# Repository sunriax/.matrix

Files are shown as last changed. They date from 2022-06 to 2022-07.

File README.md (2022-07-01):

 

# . Matrix Display Controller

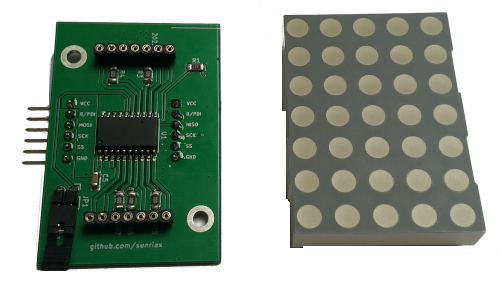
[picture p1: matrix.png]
PCB


The MDC (Matrix Display Controller) is to interact with a dot matrix display (like the [Kingbright TA20](https://at.rs-online.com/web/p/led-displays/4516650?sra=pmpn)) over `SPI` bus or `UART` (See the command list below).

# Board

| Download | Description |
|---|:---:|
| [Schematic](https://cadlab.io/project/25253/main/circuit/UENCL21hdHJpeC5raWNhZF9zY2g%3D) | Complete Schematic of the Display|
| [KiCAD](https://cadlab.io/project/25253/main/circuit/UENCL21hdHJpeC5raWNhZF9wY2I%3D) | KiCAD files |
| [Gerber](https://cadlab.io/project/25253/main/circuit/UENCL21hdHJpeC5raWNhZF9wY2I%3D) | Gerber production and drill files |

## 3D Model

| TOP | BOT |
|-----|-----|
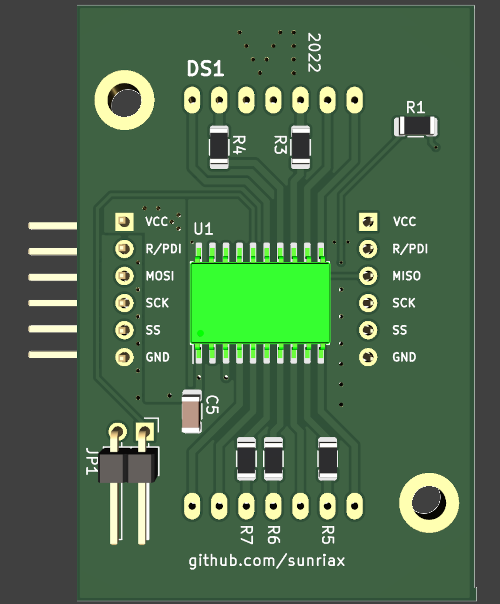
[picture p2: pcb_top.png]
PCB Top
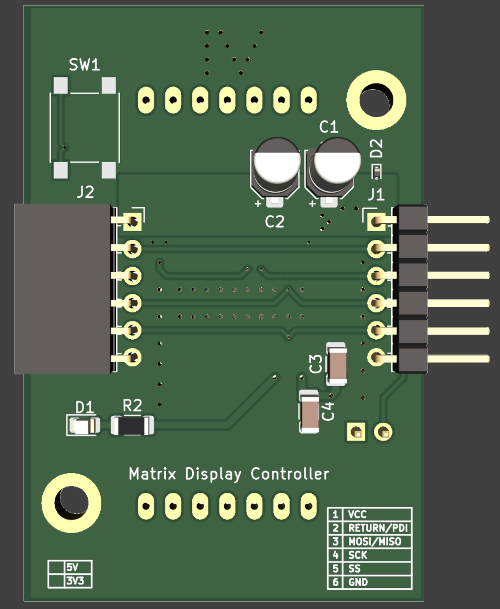
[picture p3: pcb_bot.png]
PCB Bot
|  |  | 

## Agenda

| Board | Status |
|---|:---:|
| [Schematic](https://cadlab.io/project/25253/main/circuit/UENCL21hdHJpeC5raWNhZF9zY2g%3D) | ✔️ Done |
| [Board](https://cadlab.io/project/25253/main/circuit/UENCL21hdHJpeC5raWNhZF9wY2I%3D) | ✔️ Done |
| [Partlist](./PCB/docs/matrix.csv) | ✔️ Done |
| Production | ✔️ Done |
| [Assembly](pcb.png) | ✔️ Done |
| Case | ❌ Open |

# Firmware 

| Image | Download |
|---|---|
| Display | [zip](https://github.com/sunriax/.matrix/releases/latest/download/matrix-firmware.zip) / [tar.gz](https://github.com/sunriax/.matrix/releases/latest/download/matrix-firmware.tar.gz) |
| Demo (ATmega16) | [zip](https://github.com/sunriax/.matrix/releases/latest/download/test-firmware-atmega16a.zip) / [tar.gz](https://github.com/sunriax/.matrix/releases/latest/download/test-firmware-atmega16a.tar.gz) |

# Display

The display can be driven in two modes either the standard (`spi`) mode or the `uart` mode.

## SPI mode

The display can be controlled with the `matrix` library. The library can be found in the [TEST project](./Firmware/TEST/main.c). The library is modular and can be adapted onto other plattforms. For platform adaptions the `spi` library has to be rewritten for the target platform. Currently the library can be used with an `ATmega16A`.

### Startup

``` c
// User libraries
#include "matrix/matrix.h"

// ...
int main(void)
{
	matrix_init();
	_delay_ms(1000);
	matrix_clear_all();
	_delay_ms(1000);
}
```

### Standard commands

| Command | Description |
|---|---|
| `matrix_init()` | Initializes the display |
| `matrix_buffer(0-255, ARRAY)` | Send an array (5*7) bits to a specific display |
| `matrix_buffer_all(ARRAY)` | Send an array (5*7) bits to all displays |
| `matrix_char(0-255, ASCII)` | Send an ASCII char to a specific display |
| `matrix_string(STRING)` | Send an ASCII string to a all display |
| `matrix_clear(0-255)` | Clear a specific display |
| `matrix_clear_all()` | Clear all displays |

### Speical commands

| Define | VALUE | Description |
|---|---|---|
| `MATRIX_EEPROM_CHAR0`  | `0x00`  | EEPROM address of MEMORY 0 |
| `MATRIX_EEPROM_CHAR0`  | `0x01`  | EEPROM address of MEMORY 1 |
| ... | ... | ... |
| `MATRIX_EEPROM_CHAR0`  | `0x0E`  | EEPROM address of MEMORY E |
| `MATRIX_EEPROM_CHAR0`  | `0x0F`  | EEPROM address of MEMORY F |

| Command | Description |
|---|---|
| `matrix_prom_write(0-255, DEFINE, ARRAY)` | Save an array (5*7) to the display EEPROM |
| `matrix_prom_read(0-255, DEFINE)` | Load an array from EEPROM to the display |

### Example

``` c
// TEST Connection
//
//          uC                 DISPLAY 0              DISPLAY 1
//  ~~~~~~~~~~~~~~~~~+    +~~~~~~~~~~~~~~~~~+    +~~~~~~~~~~~~~~~~~+
//    A  (M)         |    |                 |    |                 |
//    T  (E)     VCC +----+ VCC         VCC +----+ VCC         VCC |
//    M  (G)         |    |                 |    |                 |
//    E  (A)    MOSI +----+ MOSI       MISO +----+ MOSI       MISO |
//    G  (C)     SCK +----+ SCK         SCK +----+ SCK         SCK |
//    A  (A)      SS +----+ SS           SS +----+ SS           SS |
//    1  (R)     GND +----+ GND         GND +----+ GND         GND |
//    6  (D)         |    |                 |    |                 |
//    A              |    +~~~~~~~~~~~~~~~~~+    +~~~~~~~~~~~~~~~~~+
//  ~~~~~~~~~~~~~~~~~+

#define F_CPU 12000000UL    // System clock (required for delay)

// System libraries
#include <avr/io.h>
#include <util/delay.h>

// User libraries
#include "matrix/matrix.h"

// ...
int main(void)
{
	matrix_init();
	_delay_ms(1000);
	matrix_clear_all();
	_delay_ms(1000);

    unsigned char buffer[] = {
		0b01000,
		0b01000,
		0b01000,
		0b01000,
		0b01000,
		0b01000,
		0b11111
	}; 

    // Send buffer to display 0
    matrix_buffer(0, buffer);
	_delay_ms(1000);

    // Send buffer to all displays
    matrix_buffer_all(buffer);
	_delay_ms(1000);

    // Send ASCII char to display 0
    matrix_char(0, 'A');
	_delay_ms(1000);

    // Send string to displays
    matrix_string(0, "TEST");
	_delay_ms(1000);

    // Clear display 0
    matrix_clear(0);
	_delay_ms(1000);

    // Clear all displays
    matrix_clear_all();
	_delay_ms(1000);

    // !!! Only one time necessary !!!
    // !!!!!!!!!!!!!!!!!!!!!!!!!!!!!!!!!!!!!!!!!!!!!!!!!!!
    // !!! Warning:                                    !!!
    // !!! Don´t call this function in a while(1) loop !!!
    // !!! This will damage the EEPROM                 !!!
    // !!!!!!!!!!!!!!!!!!!!!!!!!!!!!!!!!!!!!!!!!!!!!!!!!!!

    // Save buffer in display EEPROM
	matrix_prom_write(0, MATRIX_EEPROM_CHAR0, buffer);
	_delay_ms(1000);

    // Read data from EEPROM
    matrix_prom_read(0, MATRIX_EEPROM_CHAR0);
	_delay_ms(1000);
}
```

## UART mode

The standard ASCII characters can also be transferred to display over UART. Therefore a special configuration is necessary. Pin `SS` should be connected to ground (`GND`) before powering the display.

``` c
// TEST Connection
//
//           DISPLAY 0              USB/UART
//      +~~~~~~~~~~~~~~~~~+   +~~~~~~~~~~~~~~~~~+
//      |                 |   |                 |
//      + VCC         VCC +---+ VCC             |
//      |                 |   |             +---+
//      + MOSI       MISO +---+ TXD         | U |
//      + SCK         SCK +   |             | S |
//  +---+ SS           SS +   |             | B |
//  +---+ GND         GND +---+ GND         +---+
//      |                 |   |                 |
//      +~~~~~~~~~~~~~~~~~+   +~~~~~~~~~~~~~~~~~+
```

Characters can be sent to the display over [TeraTerm](https://osdn.net/projects/ttssh2/releases/) or [Putty](https://www.chiark.greenend.org.uk/~sgtatham/putty/latest.html)
`UART` should contain following setup:

| Parameter | Value |
|---|---|
| Baudrate  | 9600  |
| Datasize  | 8 Bit |
| Parity | None  |
| Stopbits  | 1 |

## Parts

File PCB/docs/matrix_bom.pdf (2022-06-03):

ID Bezeichner Gehäuse | Stückzahl Bezeichnung/Wert
1 R2 | R_1206_3216Metric | 1 140 | DigiKey | RMCF1206FT140R
2 R5,R3,R4,R6,R7R_1206_3216Metric | 5 0 | Magazin -
3 JP1 | PinHeader_1x02_P2.54mm_Horizontal | 1 | RS | siehe Pos. 14
4 H1,H2 | MountingHole_3.2mm_M3_DIN965_Pad | 2 | - | -
5 C5 | C_1206_3216Metric | 1 10n | RS | 264-4141
6 DS1 | DIPS3810W50P254L3765H870Q14N | 1 TA20-11SRWA | RS | 451-6650
7 U1 | SOIC-20W_7.5x12.8mm_P1.27mm | 1 ATtiny406-S | DigiKey | ATTINY406-SNRTR-ND
8 R1 | R_1206_3216Metric | 1 330 | RS | 223-2186
9 C4,C3 | C_1206_3216Metric | 2 100n | RS | 133-5654
10 D1 | LED_0805_2012Metric | 1 LED | RS | 654-5773
11 SW1 | SW_SPST | 1 Taster SMD Megacard | RS | 479-1491
12 C2,C1 | CP_Elec_4x5.8 | 2 10u | RS | 565-633
13 J2 | PinSocket_1x06_P2.54mm_Horizontal | 1 Conn_01x06_Female | RS | 765-5676
14 J1 | PinHeader_1x06_P2.54mm_Horizontal | 1 Conn_01x06_Male | RS | 251-8654
15 | Buchsenleiste | 2 | RS | 267-7400

Anbieter und Referenz

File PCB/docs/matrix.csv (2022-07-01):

ID | Bezeichner | Gehäuse | Stückzahl | Bezeichnung | Anbieter und Referenz
1 | R2 | R_1206_3216Metric | 1 | 140 | DigiKey | RMCF1206FT140R | Digikey
2 | R5/R3/R4/R6/R7 | R_1206_3216Metric | 5 | 0
3 | JP1 | PinHeader_1x02_P2.54mm_Horizontal | 1 |  | RS | siehe Pos. 14 | RS
4 | H1/H2 | MountingHole_3.2mm_M3_DIN965_Pad | 2
5 | C5 | C_1206_3216Metric | 1 | 10n | RS | 264-4141 | RS
6 | DS1 | DIPS3810W50P254L3765H870Q14N | 1 | TA20-11SRWA | RS | 451-6650 | RS
7 | U1 | SOIC-20W_7.5x12.8mm_P1.27mm | 1 | ATtiny406-S | DigiKey | ATTINY406-SNRTR-ND | DigiKey
8 | R1 | R_1206_3216Metric | 1 | 330 | RS | 223-2186 | RS
9 | C4/C3 | C_1206_3216Metric | 2 | 100n | RS | 133-5654 | RS
10 | D1 | LED_0805_2012Metric | 1 | LED | RS | 654-5773 | RS
11 | SW1 | SW_SPST | 1 | SW_Push | RS | 479-1491 | RS
12 | C2/C1 | CP_Elec_4x5.8 | 2 | 10u | RS | 565-633 | RS
13 | J2 | PinSocket_1x06_P2.54mm_Horizontal | 1 | Conn_01x06_Female | RS | 765-5676 | RS
14 | J1 | PinHeader_1x06_P2.54mm_Horizontal | 1 | Conn_01x06_Male | RS | 251-8654 | RS
15 |  | Buchsenleiste | 2 |  | RS | 267-7400 | RS
16 |  | Leiterplatte | 50 | 76 |  |  | multi-cb

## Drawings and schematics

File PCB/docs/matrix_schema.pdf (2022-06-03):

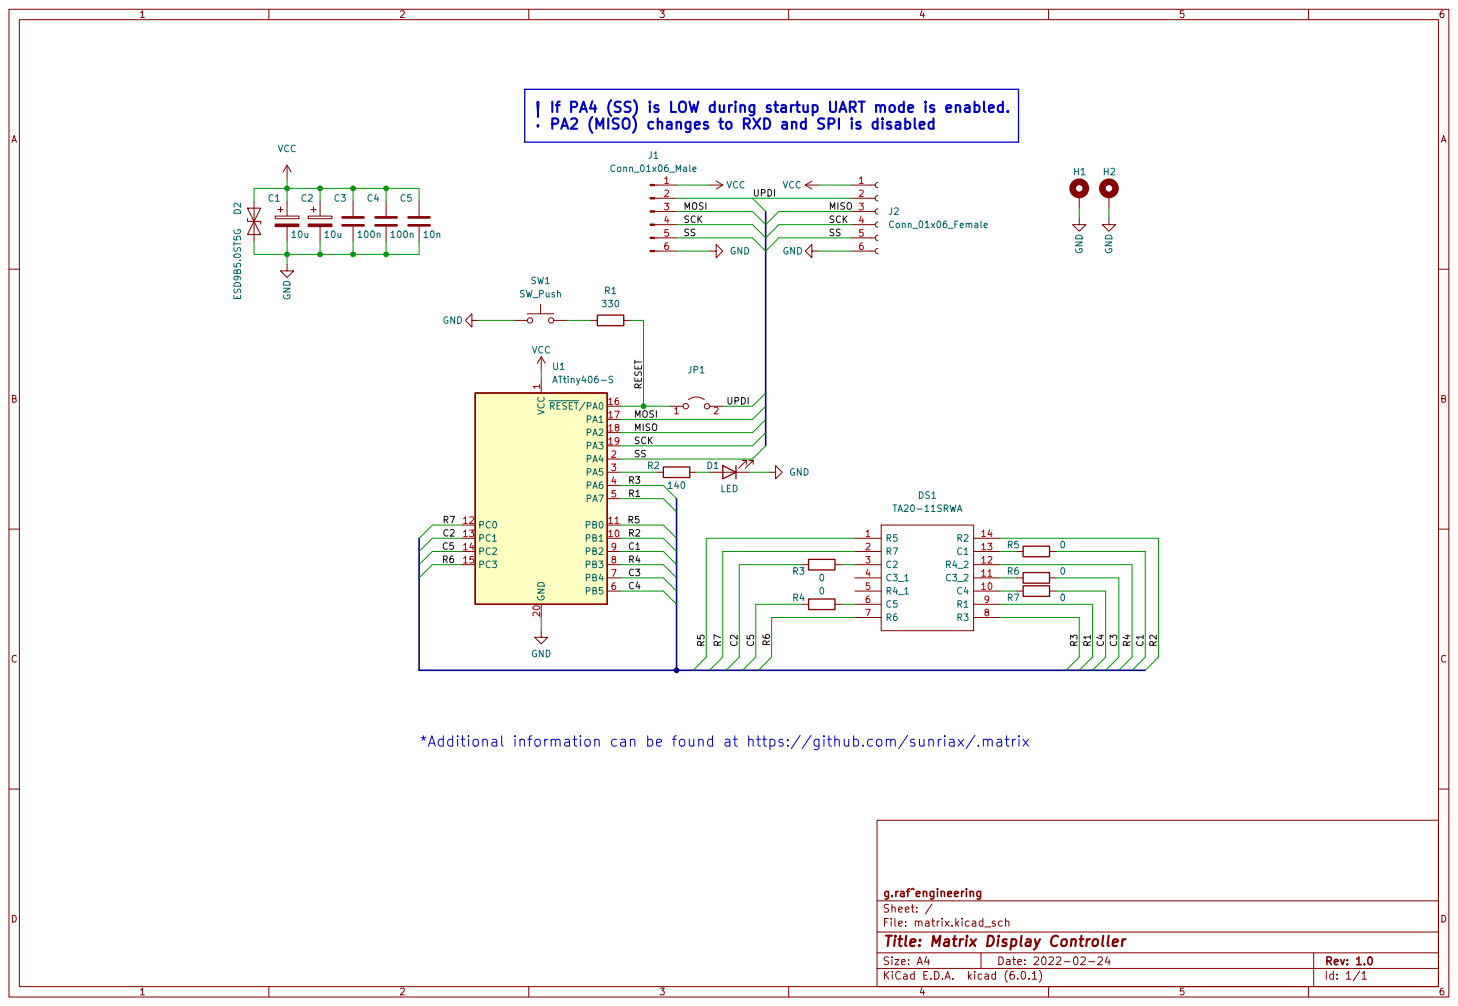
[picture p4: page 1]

If PA4 (SS) is LOW during startup UART mode is enabled.
PA2 (MISO) changes to RXD and SPI is disabled
VCCGND GND

*Additional information can be found at https://github.com/sunriax/.matrix

File: matrix.kicad_sch Sheet: / g.raf^engineering

Id: 1/1 Title: Matrix Display Controller

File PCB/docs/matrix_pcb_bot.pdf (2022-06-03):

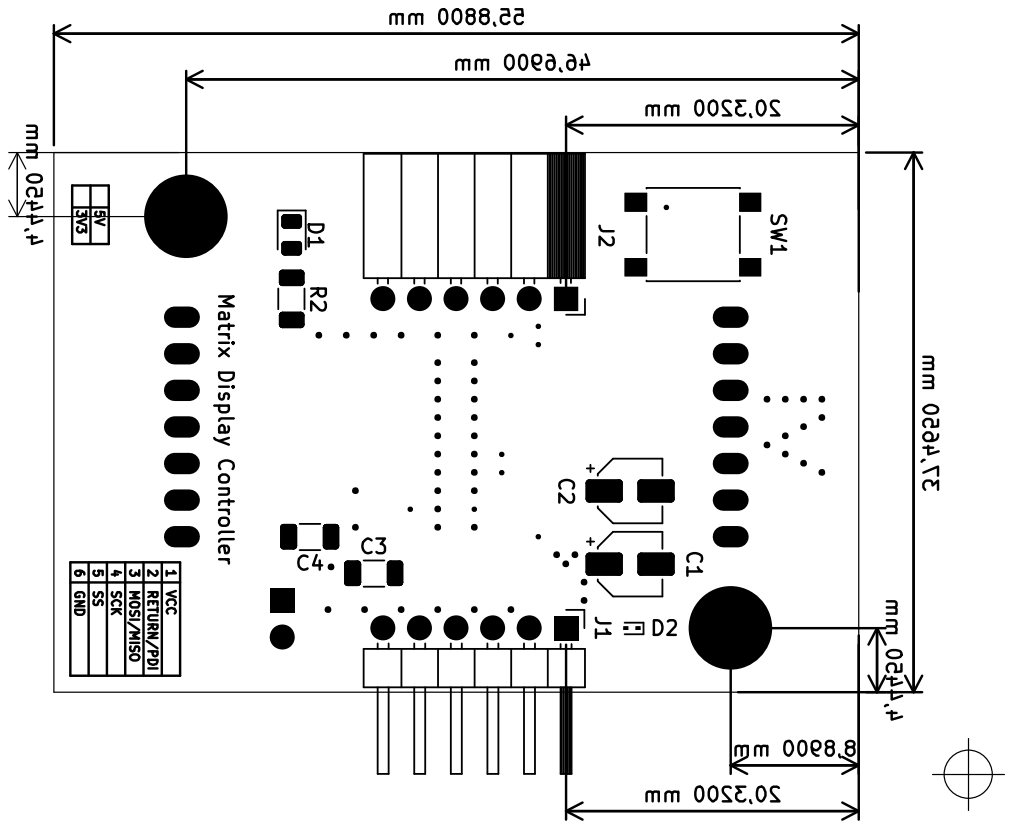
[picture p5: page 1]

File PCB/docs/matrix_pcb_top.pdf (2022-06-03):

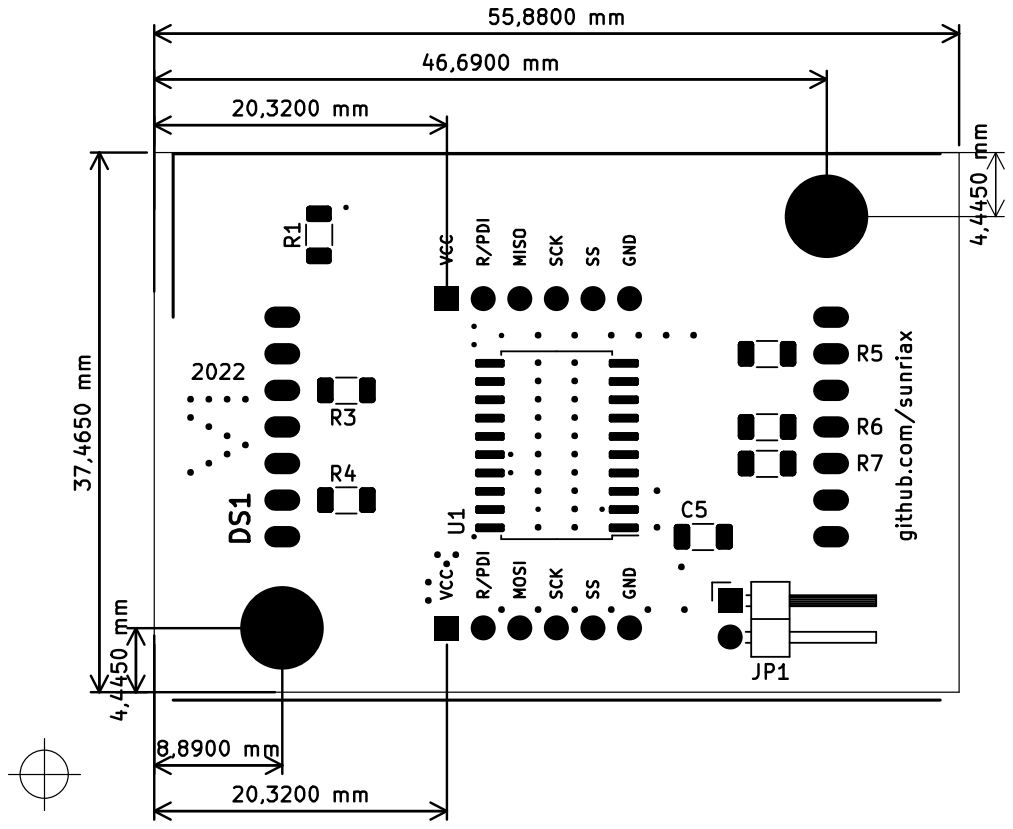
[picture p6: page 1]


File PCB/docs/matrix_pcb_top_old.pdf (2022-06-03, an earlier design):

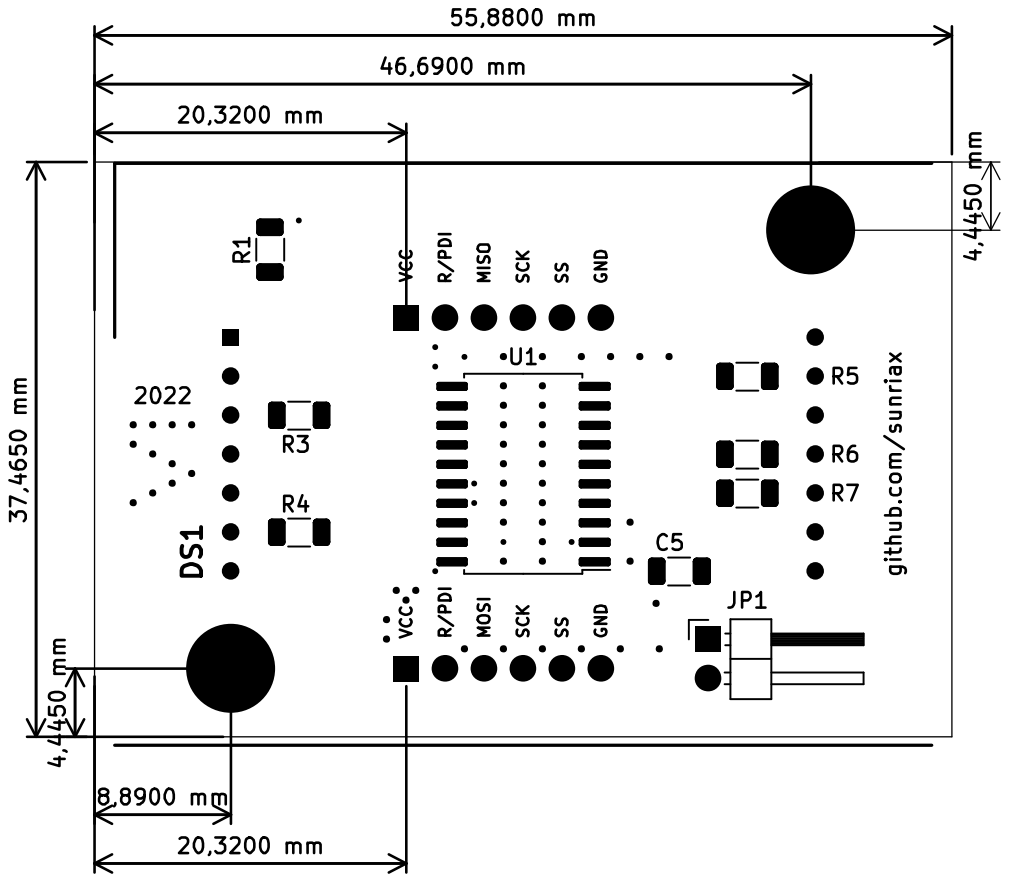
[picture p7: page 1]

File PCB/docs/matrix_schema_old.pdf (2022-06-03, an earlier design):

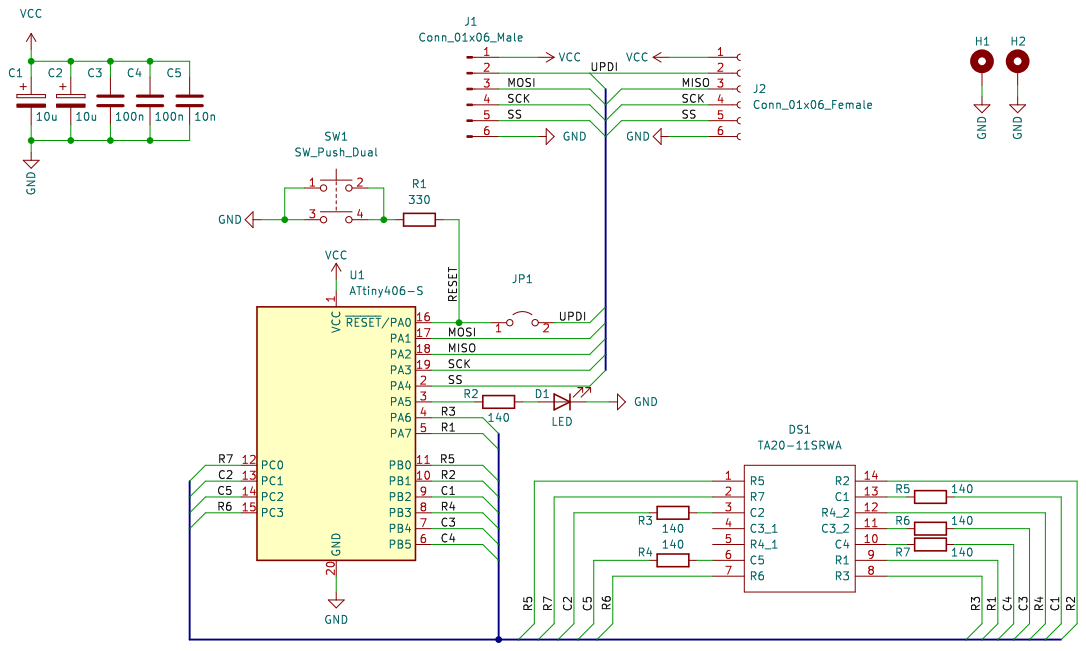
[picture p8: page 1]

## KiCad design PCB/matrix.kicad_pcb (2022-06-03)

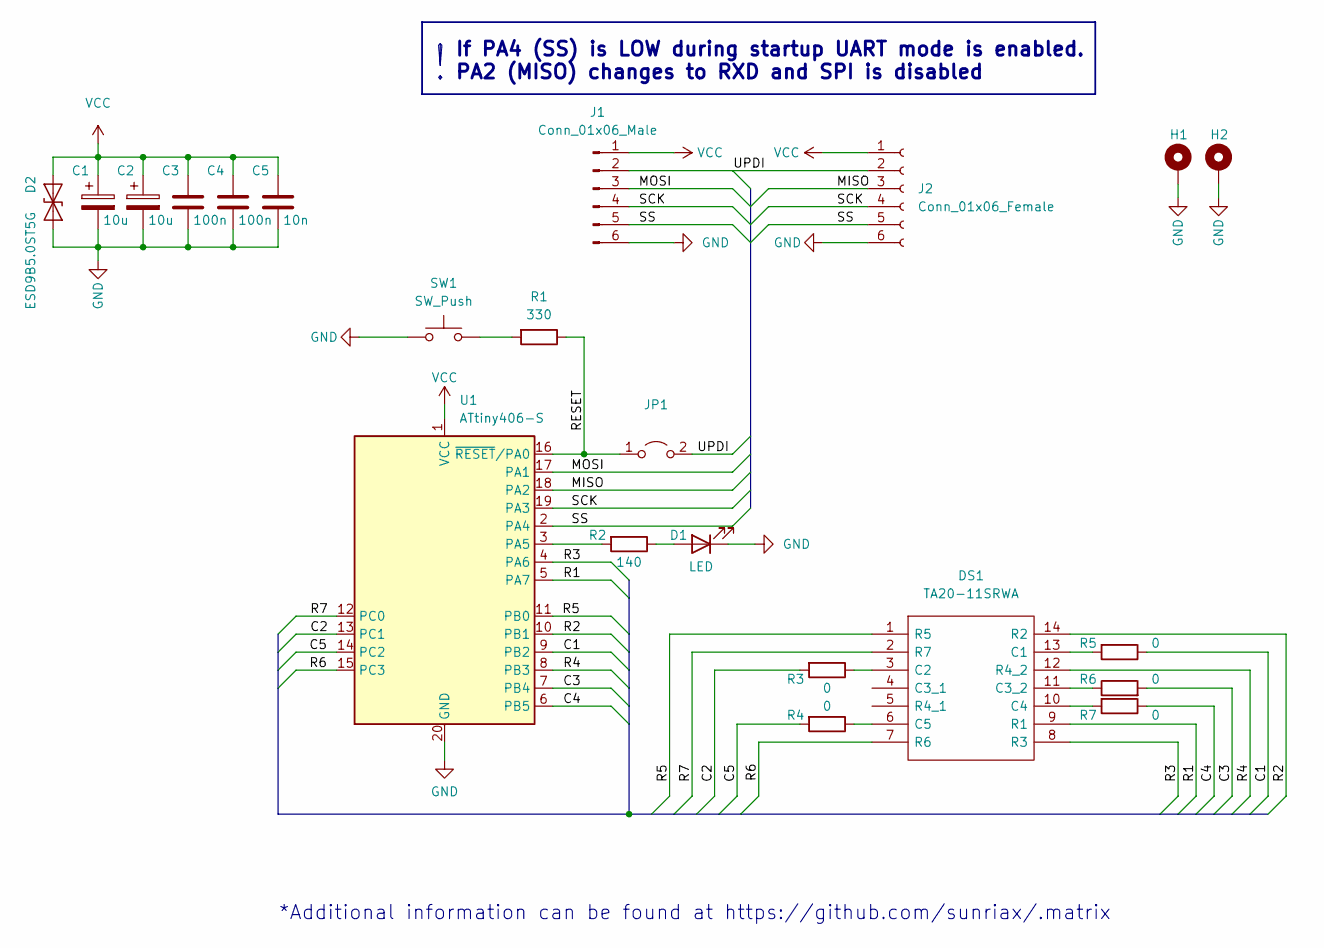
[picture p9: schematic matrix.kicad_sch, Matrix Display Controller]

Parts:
C1, C2: 10u; CP_Elec_4x5.8
C3, C4: 100n; C_1206_3216Metric
C5: 10n; C_1206_3216Metric
D1: LED; LED_0805_2012Metric
D2: ESD9B5.0ST5G; D_SOD-923
DS1: TA20-11SRWA; DIPS3810W50P254L3765H870Q14N; Manufacturer_Part_Number TA20-11SRWA; Mouser Part Number 604-TA20-11SRWA
H1, H2: MountingHole_3.2mm_M3_DIN965_Pad
J1: Conn_01x06_Male; PinHeader_1x06_P2.54mm_Horizontal
J2: Conn_01x06_Female; PinSocket_1x06_P2.54mm_Horizontal
JP1: PinHeader_1x02_P2.54mm_Horizontal
R1: 330; R_1206_3216Metric
R2: 140; R_1206_3216Metric
R3, R4, R5, R6, R7: 0; R_1206_3216Metric
SW1: SW_Push; SW_Push_1P1T_NO_6x6mm_H9.5mm
U1: ATtiny406-S; SOIC-20W_7.5x12.8mm_P1.27mm

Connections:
/C1: R5.1, U1.9 (PB2)
/C2: R3.2, U1.13 (PC1)
/C3: R6.2, U1.7 (PB4)
/C4: R7.1, U1.6 (PB5)
/C5: R4.2, U1.14 (PC2)
/MISO: J2.3, U1.18 (PA2)
/MOSI: J1.3, U1.17 (PA1)
/R1: DS1.9 (R1), U1.5 (PA7)
/R2: DS1.14 (R2), U1.10 (PB1)
/R3: DS1.8 (R3), U1.4 (PA6)
/R4: DS1.12 (R4_2), U1.8 (PB3)
/R5: DS1.1 (R5), U1.11 (PB0)
/R6: DS1.7 (R6), U1.15 (PC3)
/R7: DS1.2 (R7), U1.12 (PC0)
/RESET: JP1.1 (A), R1.1, U1.16 (~RESET/PA0)
/SCK: J1.4, J2.4, U1.19 (PA3)
/SS: J1.5, J2.5, U1.2 (PA4)
/UPDI: J1.2, J2.2, JP1.2 (B)
GND: C1.2, C2.2, C3.2, C4.2, C5.2, D1.1 (K), D2.1 (A1), H1.1, H2.1, J1.6, J2.6, SW1.1, U1.20 (GND)
unnamed: D1.2 (A), R2.1
unnamed: DS1.3 (C2), R3.1
unnamed: DS1.6 (C5), R4.1
unnamed: DS1.10 (C4), R7.2
unnamed: DS1.11 (C3_2), R6.1
unnamed: DS1.13 (C1), R5.2
unnamed: R1.2, SW1.2
unnamed: R2.2, U1.3 (PA5)
VCC: C1.1, C2.1, C3.1, C4.1, C5.1, D2.2 (A2), J1.1, J2.1, U1.1 (VCC)

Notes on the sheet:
*Additional information can be found at https://github.com/sunriax/.matrix
If PA4 (SS) is LOW during startup UART mode is enabled. PA2 (MISO) changes to RXD and SPI is disabled

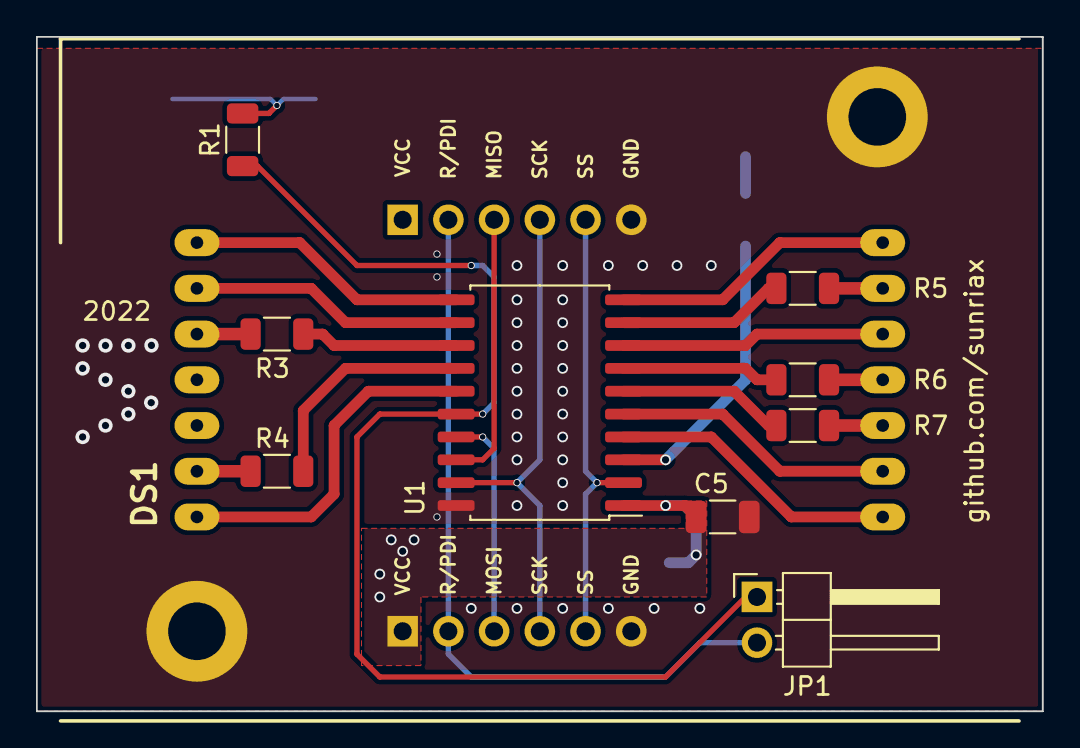
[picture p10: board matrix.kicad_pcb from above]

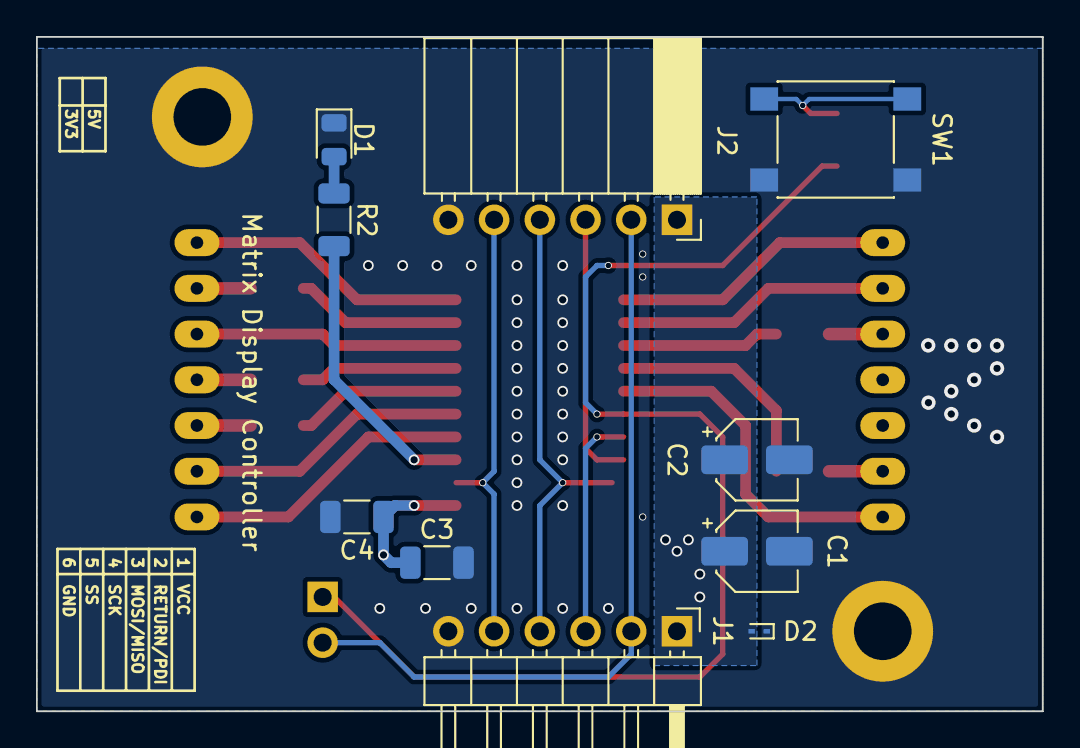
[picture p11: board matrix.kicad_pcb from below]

Board: 2 copper layers, 55.9 x 37.5 mm, 22 parts (10 on the bottom side), 28 nets.

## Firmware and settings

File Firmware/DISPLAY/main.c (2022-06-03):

/* -----------------------------------------
 * G.Raf^engineering
 * www.sunriax.at
 * -----------------------------------------
 *    Platform: .matrix display controller
 *    Hardware: ATtiny406
 * -----------------------------------------
 *     Version: 1.0 Release
 *      Author: G.Raf
 * Description:
 *   .matrix display controller firmware
 * -----------------------------------------
 */ 

#define F_CPU 20000000UL

#define BAUDRATE 9600UL
// #define USE_U2X

#ifdef USE_U2X
	#define USART0_BAUD_RATE(BAUD_RATE) ((float)(F_CPU * 64 / (8 * (float)BAUD_RATE)) + 0.5)
#else
	#define USART0_BAUD_RATE(BAUD_RATE) ((float)(F_CPU * 64 / (16 * (float)BAUD_RATE)) + 0.5)
#endif

#define TIMER_PER 0x04FF

#include <avr/io.h>
#include <avr/cpufunc.h>
#include <avr/interrupt.h>
#include <util/delay.h>

#include "matrix/matrix.h"

volatile unsigned char spi_buffer;
volatile unsigned char spi_command;
volatile unsigned char spi_pointer;

volatile unsigned char pixel_x;
volatile unsigned char pixel_y;

volatile unsigned char copy;

volatile unsigned char eeprom_save;
volatile unsigned char eeprom_load;

volatile unsigned char matrix[] = {
	0b00000,
	0b00000,
	0b00000,
	0b00000,
	0b00000,
	0b00000,
	0b00000
};

ISR(PORTA_PORT_vect)
{
	sei();	// Allow nested interrupts

	// DATA transfer led
	PORTA.OUTTGL = PIN5_bm;

	spi_pointer++;

	if(spi_pointer % 2)
	{
		spi_command = spi_buffer;
	}
	else
	{
		spi_buffer;
		spi_pointer = 0;
	
		switch (spi_command)
		{
			case 0x01:	// ROW 1
			case 0x02:	// ROW 2
			case 0x03:	// ROW 3
			case 0x04:	// ROW 4
			case 0x05:	// ROW 5
			case 0x06:	// ROW 6
			case 0x07:	// ROW 7
				matrix[(spi_command - 1)] = spi_buffer;
			break;
			case 0x08:	// Initiate ASCII copy
				copy = spi_buffer;
			break;
			case 0x09:	// CLEAR
				matrix_clear_buffer(matrix);
			break;
			case 0x10:	// Display On/Off
				if(0x01 & spi_buffer)
				{
					TCA0.SINGLE.CTRLA |= TCA_SINGLE_ENABLE_bm;
				}
				else
				{
					TCA0.SINGLE.CTRLA &= ~TCA_SINGLE_ENABLE_bm;
					matrix_row_clear();
					matrix_column_clear();
				}
			break;
			case 0x20:	// Display EEPROM
			case 0x21:
			case 0x22:
			case 0x23:
			case 0x24:
			case 0x25:
			case 0x26:
			case 0x27:
			case 0x28:
			case 0x29:
			case 0x2A:
			case 0x2B:
			case 0x2C:
			case 0x2D:
			case 0x2E:
			case 0x2F:
				eeprom_load = spi_command;
			break;
			case 0x30:	// Copy matrix content to EEPROM
			case 0x31:
			case 0x32:
			case 0x33:
			case 0x34:
			case 0x35:
			case 0x36:
			case 0x37:
			case 0x38:
			case 0x39:
			case 0x3A:
			case 0x3B:
			case 0x3C:
			case 0x3D:
			case 0x3E:
			case 0x3F:
				eeprom_save = spi_command;
			break;
			default:
			break;
		}
		
		spi_command = 0x00;
	}
	
	PORTA.INTFLAGS = PIN4_bm;
}

ISR(TCA0_OVF_vect)
{
	matrix_row_clear();
	matrix_column_clear();
	
	if(0x01 & (matrix[pixel_y]>>(4-pixel_x)))
	{
		matrix_row((6 - pixel_y));
		matrix_column((4 - pixel_x));
	}
	
	if((++pixel_x) >= 5)
	{
		pixel_x = 0;
		
		if((++pixel_y) >= 7)
		{
			pixel_y = 0;
		}
	}
	
	TCA0.SINGLE.INTFLAGS = TCA_SINGLE_OVF_bm;
}

ISR(SPI0_INT_vect)
{
	sei();	// Allow nested interrupts
	
	spi_buffer = SPI0.DATA;
	SPI0.DATA = spi_buffer;
	
	SPI0.INTFLAGS = SPI_IF_bm;
}

ISR(USART0_RXC_vect)
{
	sei();	// Allow nested interrupts
	
	PORTA.OUTTGL = PIN5_bm;
	copy = USART0.RXDATAL;
}

int main(void)
{
	// CLOCK Setup
	CCP = CCP_IOREG_gc;
	CLKCTRL.MCLKCTRLA = CLKCTRL_CLKSEL_OSC20M_gc;
	while(!(CLKCTRL.MCLKSTATUS & CLKCTRL_OSC20MS_bm));
	
	CCP = CCP_IOREG_gc;
	CLKCTRL.MCLKCTRLB = 0x00;
	CLKCTRL.OSC20MCTRLA = CLKCTRL_RUNSTDBY_bm;

	// PORT Setup
	PORTA.DIRSET = PIN5_bm;				// Set LED to output
	
	PORTA.DIRCLR = PIN4_bm;				// Set SS to input
	PORTA.PIN4CTRL = PORT_PULLUPEN_bm;	// Enable pullup on SS
	
	// DISPLAY Update
	matrix_setup();
	
	// TIMER Setup
	TCA0.SINGLE.PER = TIMER_PER;
	TCA0.SINGLE.INTCTRL = TCA_SINGLE_OVF_bm;
	TCA0.SINGLE.CTRLB = TCA_SINGLE_WGMODE_NORMAL_gc;
	TCA0.SINGLE.CTRLA = TCA_SINGLE_CLKSEL_DIV8_gc;
	
	// UART Setup
	if(!(PORTA.IN & PIN4_bm))
	{
		PORTMUX.CTRLB = PORTMUX_USART0_ALTERNATE_gc;
		
		USART0.BAUD = (unsigned int)USART0_BAUD_RATE(BAUDRATE);
		USART0.CTRLA = USART_RXCIE_bm;
		USART0.CTRLB = USART_RXEN_bm;
		
		#if USE_U2X
			USART0.CTRLB |= USART_RXMODE_CLK2X_gc;
		#endif
		
		TCA0.SINGLE.CTRLA |= TCA_SINGLE_ENABLE_bm;
	}
	//SPI Setup
	else
	{
		PORTA.DIR &= ~PIN1_bm;	// Set MOSI to input
		PORTA.DIR |= PIN2_bm;	// Set MISO to output
		PORTA.DIR &= ~PIN3_bm;	// Set SCK to input 
		
		PORTA.PIN4CTRL |= PORT_ISC_RISING_gc;
		
		SPI0.CTRLA = SPI_ENABLE_bm;
		SPI0.INTCTRL = SPI_IE_bm;
	}
	
	// Enable interrupts globally
	sei();
	
	while (1)
	{
		if(copy != '\0')
		{	
			matrix_char2buffer(copy, matrix);
			copy = '\0';
		}
		
		if(eeprom_save != 0)
		{
			matrix_buffer2eeprom(matrix, eeprom_save);
			eeprom_save = 0;
		}
		
		if(eeprom_load != 0)
		{
			matrix_eeprom2buffer(matrix, eeprom_load);
			eeprom_load = 0;
		}
	}
}

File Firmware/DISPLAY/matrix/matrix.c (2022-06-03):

/* -----------------------------------------
 * G.Raf^engineering
 * www.sunriax.at
 * -----------------------------------------
 *    Platform: .matrix display controller
 *    Hardware: ATtiny406
 * -----------------------------------------
 *     Version: 1.0 Release
 *      Author: G.Raf
 * Description:
 *   Function file .matrix display library
 * -----------------------------------------
 */

#include "matrix.h"

const __flash unsigned char A[] = {
	0b1111110,
	0b0001001,
	0b0001001,
	0b0001001,
	0b1111110
	};

const __flash unsigned char B[] = {
	0b1111111,
	0b1001001,
	0b1001001,
	0b1001001,
	0b0110110
};

const __flash unsigned char C[] = {
	0b0111110,
	0b1000001,
	0b1000001,
	0b1000001,
	0b1000001
};

const __flash unsigned char D[] = {
	0b1111111,
	0b1000001,
	0b1000001,
	0b1000001,
	0b0111110
};

const __flash unsigned char E[] = {
	0b1111111,
	0b1001001,
	0b1001001,
	0b1001001,
	0b1001001
};

const __flash unsigned char F[] = {
	0b1111111,
	0b0001001,
	0b0001001,
	0b0001001,
	0b0000001
};

const __flash unsigned char G[] = {
	0b0111110,
	0b1000001,
	0b1001001,
	0b1001001,
	0b1111001
};

const __flash unsigned char H[] = {
	0b1111111,
	0b0001000,
	0b0001000,
	0b0001000,
	0b1111111
};

const __flash unsigned char I[] = {
	0b0000000,
	0b1000001,
	0b1111111,
	0b1000001,
	0b0000000
};

const __flash unsigned char J[] = {
	0b0100000,
	0b1000000,
	0b1000000,
	0b1000000,
	0b0111111
};

const __flash unsigned char K[] = {
	0b1111111,
	0b0001000,
	0b0010100,
	0b0100010,
	0b1000001
};

const __flash unsigned char L[] = {
	0b1111111,
	0b1000000,
	0b1000000,
	0b1000000,
	0b1000000
};

const __flash unsigned char M[] = {
	0b1111111,
	0b0000010,
	0b1111100,
	0b0000010,
	0b1111111
};

const __flash unsigned char N[] = {
	0b1111111,
	0b0000010,
	0b0011100,
	0b0100000,
	0b1111111
};

const __flash unsigned char O[] = {
	0b0111110,
	0b1000001,
	0b1000001,
	0b1000001,
	0b0111110
};

const __flash unsigned char P[] = {
	0b1111111,
	0b0001001,
	0b0001001,
	0b0001001,
	0b0000110
};

const __flash unsigned char Q[] = {
	0b0111110,
	0b1000001,
	0b1010001,
	0b0100001,
	0b1011110
};

const __flash unsigned char R[] = {
	0b1111111,
	0b0001001,
	0b0011001,
	0b0101001,
	0b1000110
};

const __flash unsigned char S[] = {
	0b1000110,
	0b1001001,
	0b1001001,
	0b1001001,
	0b0110001
};

const __flash unsigned char T[] = {
	0b0000001,
	0b0000001,
	0b1111111,
	0b0000001,
	0b0000001
};

const __flash unsigned char U[] = {
	0b0111111,
	0b1000000,
	0b1000000,
	0b1000000,
	0b0111111
};

const __flash unsigned char V[] = {
	0b0011111,
	0b0100000,
	0b1000000,
	0b0100000,
	0b0011111
};

const __flash unsigned char W[] = {
	0b0111111,
	0b1000000,
	0b0111100,
	0b1000000,
	0b0111111
};

const __flash unsigned char X[] = {
	0b1000001,
	0b0100010,
	0b0011100,
	0b0100010,
	0b1000001
};

const __flash unsigned char Y[] = {
	0b0000001,
	0b0000010,
	0b1111100,
	0b0000010,
	0b0000001
};

const __flash unsigned char Z[] = {
	0b1100001,
	0b1010001,
	0b1001001,
	0b1000101,
	0b1000011
};

const __flash unsigned char ZERO[] = {
	0b0111110,
	0b1000001,
	0b1000001,
	0b1000001,
	0b0111110
};

const __flash unsigned char ONE[] = {
	0b0001000,
	0b0000100,
	0b0000010,
	0b1111111,
	0b0000000
};

const __flash unsigned char TWO[] = {
	0b1100010,
	0b1010001,
	0b1001001,
	0b1000101,
	0b1000010
};

const __flash unsigned char THREE[] = {
	0b0100010,
	0b1000001,
	0b1001001,
	0b1001001,
	0b0110110
};

const __flash unsigned char FOUR[] = {
	0b0011000,
	0b0010100,
	0b0010010,
	0b1111111,
	0b0010000
};

const __flash unsigned char FIVE[] = {
	0b1001111,
	0b1001001,
	0b1001001,
	0b1001001,
	0b0110001
};

const __flash unsigned char SIX[] = {
	0b0111110,
	0b1001001,
	0b1001001,
	0b1001001,
	0b0110000
};

const __flash unsigned char SEVEN[] = {
	0b1000001,
	0b0100001,
	0b0010001,
	0b0001001,
	0b0000111
};

const __flash unsigned char EIGHT[] = {
	0b0110110,
	0b1001001,
	0b1001001,
	0b1001001,
	0b0110110
};

const __flash unsigned char NINE[] = {
	0b1000110,
	0b1001001,
	0b1001001,
	0b1001001,
	0b0111110
};

const __flash unsigned char SPACE[] = {
	0b0000000,
	0b0000000,
	0b0000000,
	0b0000000,
	0b0000000
};

const __flash unsigned char EXCLAMATIONMARK[] = {
	0b0000000,
	0b0000000,
	0b1011111,
	0b0000000,
	0b0000000
};

const __flash unsigned char QUOTATIONMARK[] = {
	0b0000000,
	0b0000011,
	0b0000000,
	0b0000011,
	0b0000000
};

const __flash unsigned char HASHTAG[] = {
	0b0010100,
	0b1111111,
	0b0010100,
	0b1111111,
	0b0010100
};

const __flash unsigned char DOLLAR[] = {
	0b0100100,
	0b0101010,
	0b1111111,
	0b0101010,
	0b0010010
};

const __flash unsigned char PERCENT[] = {
	0b0100000,
	0b0010100,
	0b0001000,
	0b0010100,
	0b0000010
};

const __flash unsigned char AND[] = {
	0b0110110,
	0b1001101,
	0b1010010,
	0b0100000,
	0b1010000
};

const __flash unsigned char SINGLEQUOTE[] = {
	0b0000000,
	0b0000000,
	0b0000011,
	0b0000000,
	0b0000000
};

const __flash unsigned char BRACEOPEN[] = {
	0b0111110,
	0b1000001,
	0b1000001,
	0b0000000,
	0b0000000
};

const __flash unsigned char BRACECLOSE[] = {
	0b0000000,
	0b0000000,
	0b1000001,
	0b1000001,
	0b0111110
};

const __flash unsigned char STAR[] = {
	0b0000000,
	0b0000000,
	0b0000101,
	0b0000010,
	0b0000101
};

const __flash unsigned char PLUS[] = {
	0b0001000,
	0b0001000,
	0b0111110,
	0b0001000,
	0b0001000
};

const __flash unsigned char COMMA[] = {
	0b0000000,
	0b1000000,
	0b0100000,
	0b0000000,
	0b0000000
};

const __flash unsigned char MINUS[] = {
	0b0001000,
	0b0001000,
	0b0001000,
	0b0001000,
	0b0001000
};

const __flash unsigned char DOT[] = {
	0b0000000,
	0b0000000,
	0b1000000,
	0b0000000,
	0b0000000
};

const __flash unsigned char SLASH[] = {
	0b0100000,
	0b0010000,
	0b0001000,
	0b0000100,
	0b0000010
};

const __flash unsigned char COLON[] = {
	0b0000000,
	0b0000000,
	0b0100100,
	0b0000000,
	0b0000000
};

const __flash unsigned char SEMICOLON[] = {
	0b0000000,
	0b1000000,
	0b0100100,
	0b0000000,
	0b0000000
};

const __flash unsigned char LOWERTHAN[] = {
	0b0000000,
	0b0001000,
	0b0010100,
	0b0100010,
	0b0000000
};

const __flash unsigned char EQUAL[] = {
	0b0000000,
	0b0010100,
	0b0010100,
	0b0010100,
	0b0000000
};

const __flash unsigned char GREATERTHAN[] = {
	0b0000000,
	0b0100010,
	0b0010100,
	0b0001000,
	0b0000000
};

const __flash unsigned char QUESTIONMARK[] = {
	0b0000010,
	0b0000001,
	0b1011001,
	0b0001001,
	0b0000110
};

const __flash unsigned char AT[] = {
	0b0110010,
	0b1001001,
	0b1111001,
	0b1000001,
	0b1111110
};

const __flash unsigned char SQUAREBRACEOPEN[] = {
	0b0000000,
	0b1111111,
	0b1000001,
	0b1000001,
	0b0000000
};

const __flash unsigned char BACKSLASH[] = {
	0b0000010,
	0b0000100,
	0b0001000,
	0b0010000,
	0b0100000
};

const __flash unsigned char SQUAREBRACECLOSE[] = {
	0b0000000,
	0b1000001,
	0b1000001,
	0b1111111,
	0b0000000
};

const __flash unsigned char POWEROF[] = {
	0b0000000,
	0b0000010,
	0b0000001,
	0b0000010,
	0b0000000
};

const __flash unsigned char UNDERLINE[] = {
	0b1000000,
	0b1000000,
	0b1000000,
	0b1000000,
	0b1000000
};
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

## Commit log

2022-02-25 Add projects
    [matrix.kicad_pcb, matrix.kicad_sch]
2022-03-03 Extend firmware
    [matrix.kicad_pcb]
2022-03-03 Swap EEPROM display/save command
    [main.c]
2022-03-03 Add UART mode
2022-03-10 Update PCB TA20 pads
    [matrix.kicad_pcb]
2022-04-01 Code refactoring
    [matrix.kicad_pcb, matrix.kicad_sch]
2022-04-01 Optimized PCB
    [matrix.kicad_pcb]
2022-04-01 Add UART support
2022-04-06 Change SPI protocol
2022-07-01 Update partlist
    [matrix.csv]

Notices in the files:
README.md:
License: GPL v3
